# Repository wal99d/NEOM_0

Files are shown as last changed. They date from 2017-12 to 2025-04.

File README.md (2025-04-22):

NEOM_IoT
=======
This repo contains all design file for NOEM_IoT v0 Rev2.0 hardware along with its firmware. 

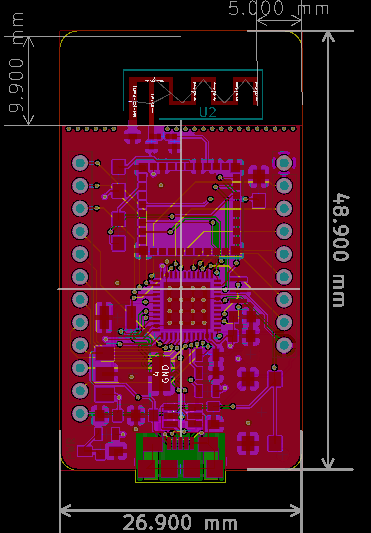
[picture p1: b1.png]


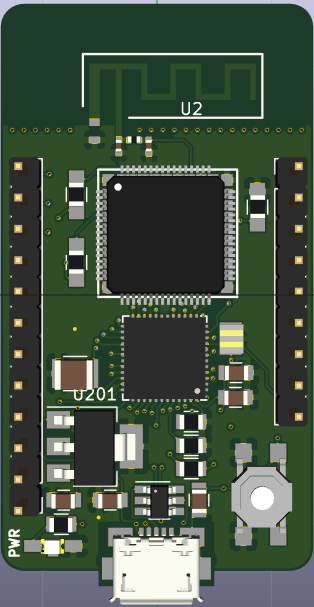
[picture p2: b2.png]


It's built with simplicity in mind using new STM32F401CEU6 MCU which have below 
> ***features:***
> - Core is ARM 32-bit Cortex-M4 with FPU.
> - Power required between 1.7v to 3.6V.
> - Up to 4 SPI
> - Up to 3 I2C
> - Up to 3 USART
> - 12 bits ADC up to 16 channels.
> - Up to 11 Timers
> - 512KB Flash and 96Kbyte SRAM which is very useful for specialized IoT applications.
> - USB 2.0 Full Speed Support.
> - Debug mode in Serial wire debug (SWD).

***TODO:***

: Firmware

***Author:***
[@wal99d](https://twitter.com/wal99d)

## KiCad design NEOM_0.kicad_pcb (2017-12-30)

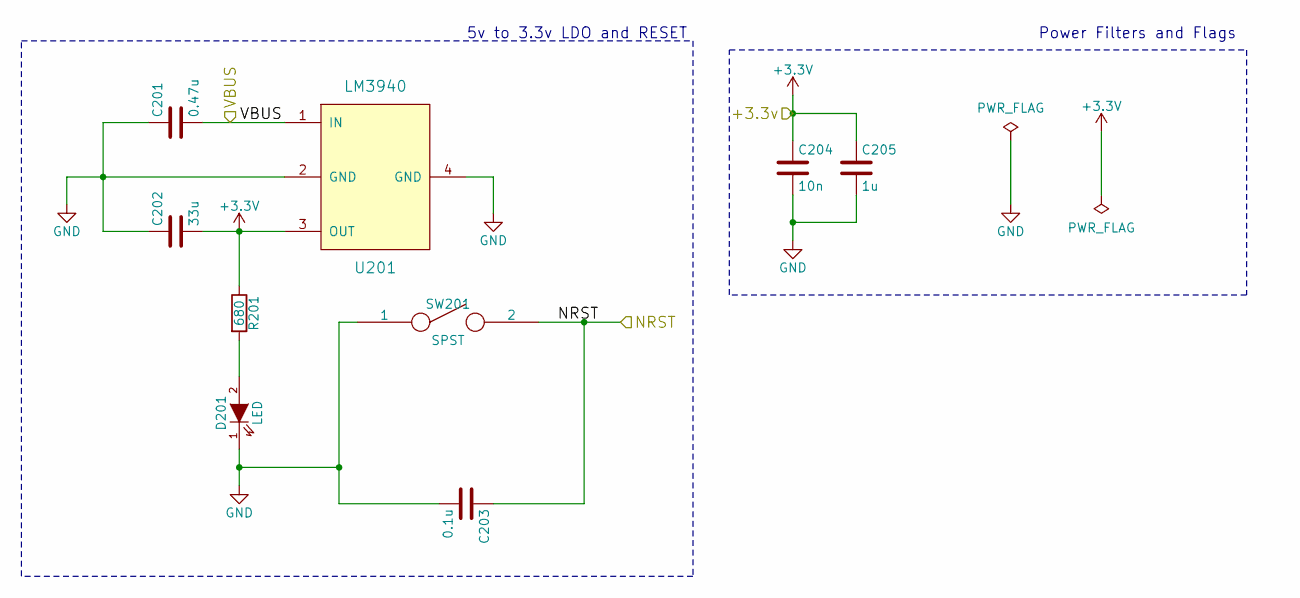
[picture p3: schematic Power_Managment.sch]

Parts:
C201: 0.47u; C_0805; ManufacturerPartNumber GRM21BR71H474KA88K; DigiKeyPartNumber 490-8319-1-ND
C202: 33u; C_0805; ManufacturerPartNumber C2012X5R0J336M125AC; DigiKeyPartNumber 445-5986-1-ND
C203: 0.1u; C_0805; ManufacturerPartNumber 08055C104KAT2A; DigiKeyPartNumber 478-1395-1-ND
C204: 10n; C_0805; ManufacturerPartNumber CC0805KRX7R9BB103; DigiKeyPartNumber 311-1136-1-ND
C205: 1u; C_0805; ManufacturerPartNumber GRM21BR71C105KA01L; DigiKeyPartNumber 490-1691-1-ND
D201: LED; 0805_LED; ManufacturerPartNumber SML-LXR85GC-TR; DigiKeyPartNumber 67-1557-1-ND
R201: 680; R_0805; ManufacturerPartNumber RC0805JR-07680RL; DigiKeyPartNumber 311-680ARCT-ND
SW201: SPST; SW_SPST; Manufacturer Part Number TL3305AF260QG; Digi-Key Part Number EG5353CT-ND
U201: LM3940; SOT-223; ManufacturerPartNumber LM3940IMPX-3.3/NOPB; DigiKeyPartNumber LM3940IMPX-3.3/NOPBCT-ND

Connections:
+3V3: C202.2, C204.1, C205.1, R201.1, U201.3 (OUT); also elsewhere on the board
/Power_Managment/NRST: C203.1, SW201.2; also elsewhere on the board
/Power_Managment/VBUS: C201.2, U201.1 (IN); also elsewhere on the board
GND: C201.1, C202.1, C203.2, C204.2, C205.2, D201.1 (K), SW201.1, U201.2 (GND), U201.4 (GND); also elsewhere on the board
unnamed: D201.2 (A), R201.2

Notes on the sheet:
5v to 3.3v LDO and RESET
Power Filters and Flags

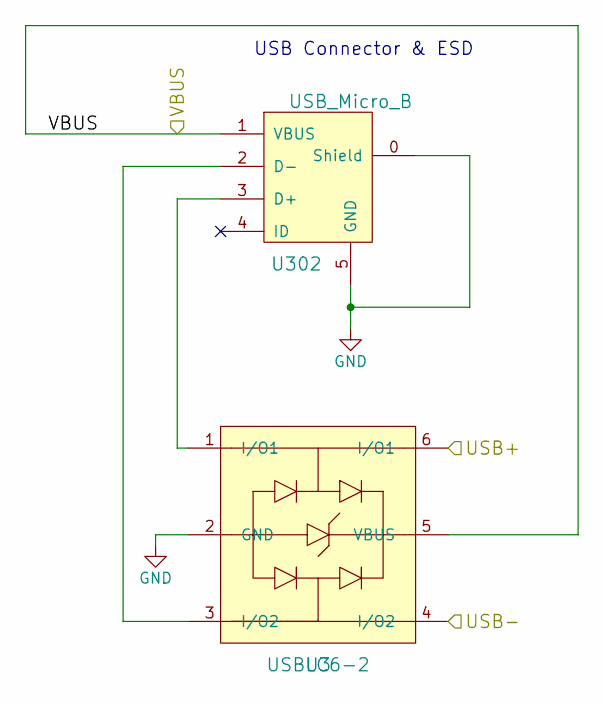
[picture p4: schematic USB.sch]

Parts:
U3: USBLC6-2; SOT-23-6_Handsoldering
U302: USB_Micro_B; MICRO_USB_B_Type; ManufacturerPartNumber 10118192-0001LF; DigiKeyPartNumber 609-4613-1-ND

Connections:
/Power_Managment/VBUS: U3.5 (VBUS), U302.1 (VBUS); also elsewhere on the board
/STM32F401CEU6/USB+: U3.6 (I/O1); also elsewhere on the board
/STM32F401CEU6/USB-: U3.4 (I/O2); also elsewhere on the board
GND: U3.2 (GND), U302.0 (Shield), U302.5 (GND); also elsewhere on the board
unnamed: U3.1 (I/O1), U302.3 (D+)
unnamed: U3.3 (I/O2), U302.2 (D-)

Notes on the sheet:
USB Connector & ESD

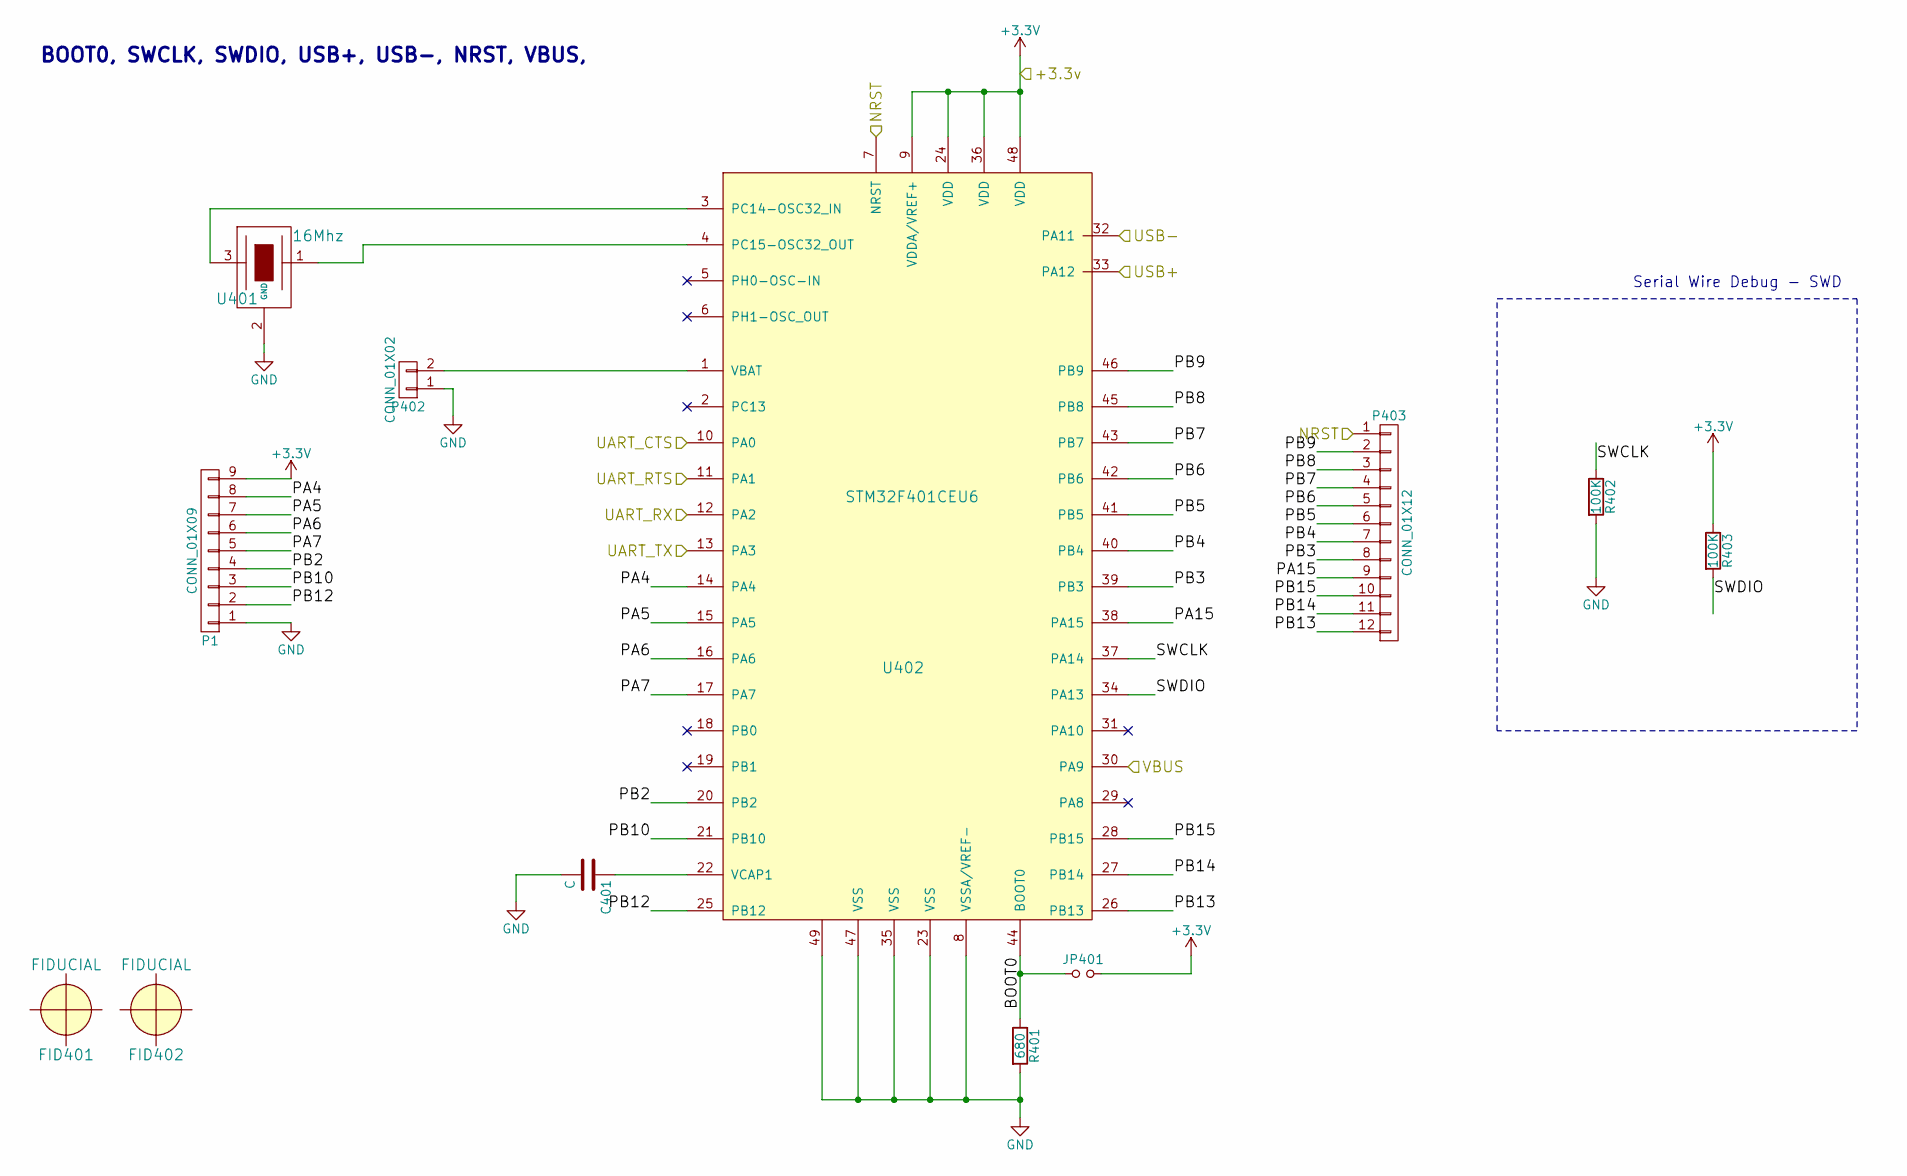
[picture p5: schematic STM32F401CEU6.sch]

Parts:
C401: C; C_1210
FID401, FID402: FIDUCIAL; MF_Aesthetics-FIDUCIAL_100MIL
JP401: Jumper_NO_Small; JUMPER-SOLDER-SMD
P1: CONN_01X09; Pin_Header_Straight_1x09_Pitch2.54mm
P402: CONN_01X02; s2b-ph-sm4-tb; Manufacturer Part Number S2B-PH-SM4-TB(LF)(SN); Digi-Key Part Number 455-1749-1-ND
P403: CONN_01X12; Pin_Header_Straight_1x12_Pitch2.54mm
R401: 680; R_0805; ManufacturerPartNumber RC0805JR-07680RL; DigiKeyPartNumber 311-680ARCT-ND
R402, R403: 100K; R_0805; ManufacturerPartNumber RC0805FR-07100KL; DigiKeyPartNumber 311-100KCRCT-ND
U401: 16Mhz; ManufacturerPartNumber CSTCE16M0V53-R0; DigiKeyPartNumber 490-1198-1-ND
U402: STM32F401CEU6; QFN-48-1EP_7x7mm_Pitch0.5mm; Manufacturer Part Number STM32F401CEU6; Digi-Key Part Number 497-17427-ND

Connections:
+3V3: JP401.2, P1.9, R403.1, U402.9 (VDDA/VREF+), U402.24 (VDD), U402.36 (VDD), U402.48 (VDD); also elsewhere on the board
/Power_Managment/NRST: P403.1, U402.7 (NRST); also elsewhere on the board
/Power_Managment/VBUS: U402.30 (PA9); also elsewhere on the board
/STM32F401CEU6/BOOT0: JP401.1, R401.1, U402.44 (BOOT0)
/STM32F401CEU6/PA4: P1.8, U402.14 (PA4)
/STM32F401CEU6/PA5: P1.7, U402.15 (PA5)
/STM32F401CEU6/PA6: P1.6, U402.16 (PA6)
/STM32F401CEU6/PA7: P1.5, U402.17 (PA7)
/STM32F401CEU6/PA15: P403.9, U402.38 (PA15)
/STM32F401CEU6/PB2: P1.4, U402.20 (PB2)
/STM32F401CEU6/PB3: P403.8, U402.39 (PB3)
/STM32F401CEU6/PB4: P403.7, U402.40 (PB4)
/STM32F401CEU6/PB5: P403.6, U402.41 (PB5)
/STM32F401CEU6/PB6: P403.5, U402.42 (PB6)
/STM32F401CEU6/PB7: P403.4, U402.43 (PB7)
/STM32F401CEU6/PB8: P403.3, U402.45 (PB8)
/STM32F401CEU6/PB9: P403.2, U402.46 (PB9)
/STM32F401CEU6/PB10: P1.3, U402.21 (PB10)
/STM32F401CEU6/PB12: P1.2, U402.25 (PB12)
/STM32F401CEU6/PB13: P403.12, U402.26 (PB13)
/STM32F401CEU6/PB14: P403.11, U402.27 (PB14)
/STM32F401CEU6/PB15: P403.10, U402.28 (PB15)
/STM32F401CEU6/SWCLK: R402.1, U402.37 (PA14)
/STM32F401CEU6/SWDIO: R403.2, U402.34 (PA13)
/STM32F401CEU6/UART_CTS: U402.10 (PA0); also elsewhere on the board
/STM32F401CEU6/UART_RTS: U402.11 (PA1); also elsewhere on the board
/STM32F401CEU6/UART_RX: U402.12 (PA2); also elsewhere on the board
/STM32F401CEU6/UART_TX: U402.13 (PA3); also elsewhere on the board
/STM32F401CEU6/USB+: U402.33 (PA12); also elsewhere on the board
/STM32F401CEU6/USB-: U402.32 (PA11); also elsewhere on the board
GND: C401.2, P1.1, P402.1, R401.2, R402.2, U401.2 (GND), U402.8 (VSSA/VREF-), U402.23 (VSS), U402.35 (VSS), U402.47 (VSS), U402.49; also elsewhere on the board
unnamed: C401.1, U402.22 (VCAP1)
unnamed: P402.2, U402.1 (VBAT)
unnamed: U401.1, U402.4 (PC15-OSC32_OUT)
unnamed: U401.3, U402.3 (PC14-OSC32_IN)

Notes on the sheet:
Serial Wire Debug - SWD
BOOT0, SWCLK, SWDIO, USB+, USB-, NRST, VBUS,

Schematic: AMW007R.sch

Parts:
C1, C2: NF; C_0402_NoSilk
R1, R3: 100k; R_0805_HandSoldering
R2: 1k; R_0805_HandSoldering
R4: 0; R_0402_NoSilk
U1: AMW007R
U2: 2.4Ghz_Ant1; 2.4Ghz_PCB_Antenna1

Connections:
+3V3: R3.2, U1.38; also elsewhere on the board
/STM32F401CEU6/UART_CTS: U1.27; also elsewhere on the board
/STM32F401CEU6/UART_RTS: U1.28; also elsewhere on the board
/STM32F401CEU6/UART_RX: U1.7; also elsewhere on the board
/STM32F401CEU6/UART_TX: U1.8; also elsewhere on the board
GND: C1.2, C2.2, R1.2, U1.1, U1.10, U1.20, U1.29, U1.31, U1.33, U1.37, U2.2; also elsewhere on the board
unnamed: C1.1, R4.2, U1.32
unnamed: C2.1, R4.1, U2.1
unnamed: R1.1, U1.5
unnamed: R2.1, U1.3
unnamed: R2.2, U1.26
unnamed: R3.1, U1.34

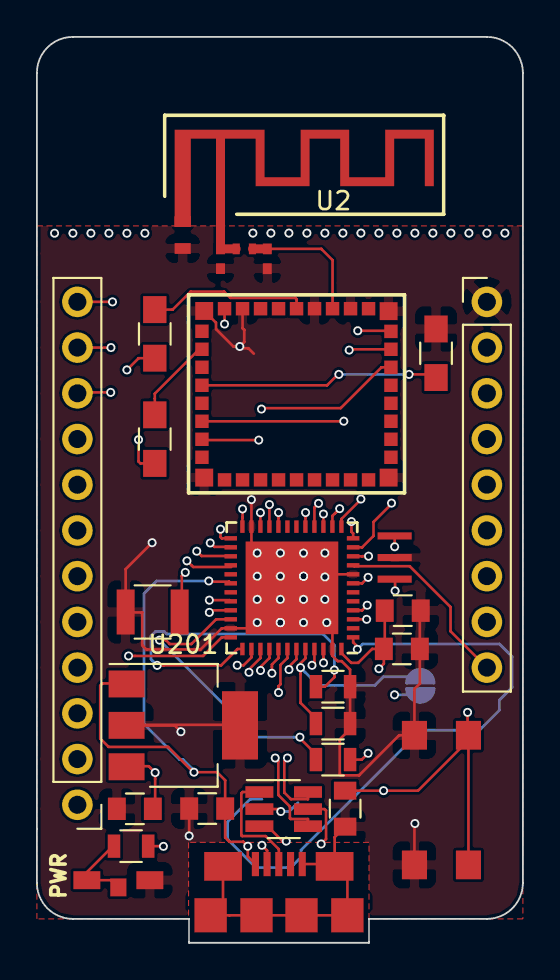
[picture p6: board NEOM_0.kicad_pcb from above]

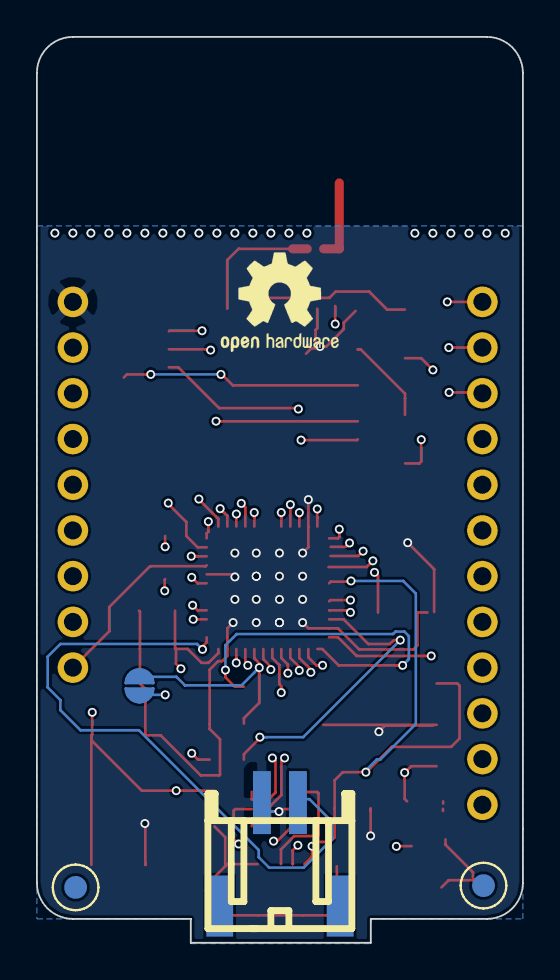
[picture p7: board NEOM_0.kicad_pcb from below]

Board: 4 copper layers, 27.0 x 50.3 mm, 31 parts (4 on the bottom side), 44 nets.

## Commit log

2017-11-19 First Commit..
    [NEOM_0.kicad_pcb, NEOM_0.sch]
2017-11-20 Updated the PCB unconnected GND pad..
    [NEOM_0-B.Cu.gbr, NEOM_0-B.Mask.gbr, NEOM_0-B.Paste.gbr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]
2017-11-21 Added BAT pin for external battery board..
    [NEOM_0-B.Cu.gbr, NEOM_0-B.Mask.gbr, NEOM_0-B.Paste.gbr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]
2017-11-23 Updated PCB with logo..
    [NEOM_0-B.Cu.gbr, NEOM_0-B.Mask.gbr, NEOM_0-B.Paste.gbr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]
2017-11-24 Updated PCB with deminsion and Fab layer..
    [NEOM_0-B.Cu.gbr, NEOM_0-B.Mask.gbr, NEOM_0-B.Paste.gbr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]
2017-11-24 Updated PCB with Footprint Fab..
    [NEOM_0-B.Cu.gbr, NEOM_0-B.Mask.gbr, NEOM_0-B.Paste.gbr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]
2017-11-25 Updated PCB: added defferintial pair routing to USB+/-...
    [NEOM_0-B.Cu.gbr, NEOM_0-B.Mask.gbr, NEOM_0-B.Paste.gbr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]
2017-11-25 Added Board Mechnical Dimensions...
    [NEOM_0.kicad_pcb]
2017-12-13 Added modified files..
    [NEOM_0.sch, Power_Managment.sch, STM32F070F6P6.sch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]
2017-12-13 Removed non needed files...
    [NEOM_0-B.Cu.gbr, NEOM_0-B.Mask.gbr, NEOM_0-B.Paste.gbr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]
2017-12-25 Updated to Rev2.0
    [AMW007R.sch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]

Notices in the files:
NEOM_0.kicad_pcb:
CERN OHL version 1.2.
